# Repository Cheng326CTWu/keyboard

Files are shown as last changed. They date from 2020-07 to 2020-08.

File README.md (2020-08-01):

# 65% keyboard

## Overview

This project was made with the intention of familiarizing myself with the work flow of KiCad. It was also a way to re-learn concepts for schematic captures and the different considerations when laying out a PCB. This repo contains a 65% keyboard PCB design made by referencing tutorials and modifying with new components.

## Software Requirement

* KiCAD

## Tutorial Reference Links

* [RuiQiMao's keyboard tutorial](https://github.com/ruiqimao/keyboard-pcb-guide)
* [ai03's keyboard tutorial](https://wiki.ai03.com/books/pcb-design/page/pcb-guide-part-1---preparations)

## Reference Links

* [Discipline's keyboard repo](https://github.com/coseyfannitutti/discipline)
* [Layer definition in KiCad](https://forum.kicad.info/t/what-is-the-meaning-of-the-layers-in-pcb-new-and-in-the-footprint-editor/9688)
* [BOM in KiCad](https://forum.kicad.info/t/how-to-create-a-bill-of-materials-bom/12346)

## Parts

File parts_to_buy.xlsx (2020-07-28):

Components | Quantity | Value | Package | Sample parts link | Comment
C1 | 1 | 1uF | 0805 | https://www.digikey.ca/en/products/detail/samsung-electro-mechanics/CL21B105KAFNNNE/3889152
C2, C3, C4, C5, C9 | 5 | 0.1uF | 0805 | https://www.digikey.ca/en/products/detail/samsung-electro-mechanics/CL21B104MBCNNNC/3890536
C6 | 1 | 4.7uF | 0805 | https://www.digikey.ca/en/products/detail/yageo/CC0805KKX5R5BB475/2345240
C7, C8 | 2 | 22pF | 0805 | https://www.digikey.ca/en/products/detail/samsung-electro-mechanics/CL21C220JB61PNC/3890691
D1, D2, D3, D4, D5, D6, D7, D8, D9, D10, D11, D12, D13, D14, D15, D16, D17, D18, D19, D20, D21, D22, D23, D24, D25, D26, D27, D28, D29, D30, D31, D32, D33, D34, D35, D36, D37, D38, D39, D40, D41, D42, D43, D44, D45, D46, D47, D48, D49, D50, D51, D52, D53, D54, D55, D56, D57, D58, D59, D60, D61, D62, D63, D64, D65, D66 | 66 | SOD-123 | SOD-123 | https://www.digikey.com/product-detail/en/micro-commercial-co/1N4148W-TP/1N4148WTPMSCT-ND/717311
D67 | 1 | LED | 0805 | https://www.digikey.ca/en/products/detail/broadcom-limited/HSMG-C170/637695
D68, D69 | 2 | 3.6V | 0805 | https://www.digikey.ca/en/products/detail/diodes-incorporated/BZT52C3V6-7-F/814990
 |  |  |  | https://www.digikey.ca/en/products/detail/rohm-semiconductor/RSA5MGTR/2331707 | This one is alternative, as the breakdown voltage range is a bit too big.
F1 | 1 | 500mA | 1206 | https://www.digikey.ca/en/products/detail/bel-fuse-inc/0ZCJ0050AF2E/4156312
J1 | 1 | USB_C_Receptacle | GCT USB4085 | https://www.digikey.ca/en/products/detail/gct/USB4085-GF-A/9859733
MX1, MX2, MX3, MX4, MX5, MX6, MX7, MX8, MX9, MX10, MX11, MX12, MX13, MX16, MX17, MX18, MX19, MX20, MX21, MX22, MX23, MX24, MX25, MX26, MX27, MX30, MX31, MX32, MX33, MX34, MX35, MX36, MX37, MX38, MX39, MX40, MX42, MX44, MX45, MX46, MX47, MX48, MX49, MX50, MX51, MX52, MX53, MX55, MX56, MX58, MX64, MX65, MX66 | 53 | MX-NoLED
MX14 | 1 | MX-NoLED
MX15, MX28 | 2 | MX-NoLED
MX29 | 1 | MX-NoLED
MX41, MX43, MX54 | 3 | MX-NoLED
MX57, MX59, MX61, MX62, MX63 | 5 | MX-NoLED
MX60 | 1 | MX-NoLED
R1, R4 | 2 | 10k | 0805 | https://www.digikey.com/product-detail/en/panasonic-electronic-components/ERA-6AEB103V/P10KDACT-ND/1465971
R2, R3 | 2 | 22 | 0805 | https://www.digikey.com/product-detail/en/panasonic-electronic-components/ERJ-6GEYJ220V/P22ACT-ND/87316
R5, R6 | 2 | 5.1k | 0805 | https://www.digikey.ca/en/products/detail/yageo/RT0805DRE075K1L/1078777
R7, R8 | 2 | 1.5k | 0805 | https://www.digikey.ca/en/products/detail/yageo/RE0805FRE071K5L/5923530
SW1 | 1 | SW_Push | 5.2x5.2mm | https://www.digikey.ca/en/products/detail/c-k/RS-187R05A2-DS-MT-RT/2747199
U1 | 1 | ATmega32U4-AU | 44TQFP 10x10mm | https://www.digikey.ca/en/products/detail/microchip-technology/ATMEGA32U4-AU/1914602
Y1 | 1 | 16MHz | 3.2x2.5mm 4 pads | https://www.digikey.ca/en/products/detail/kyocera-international-inc-electronic-components/CX3225SB16000D0GZJC1/5995241

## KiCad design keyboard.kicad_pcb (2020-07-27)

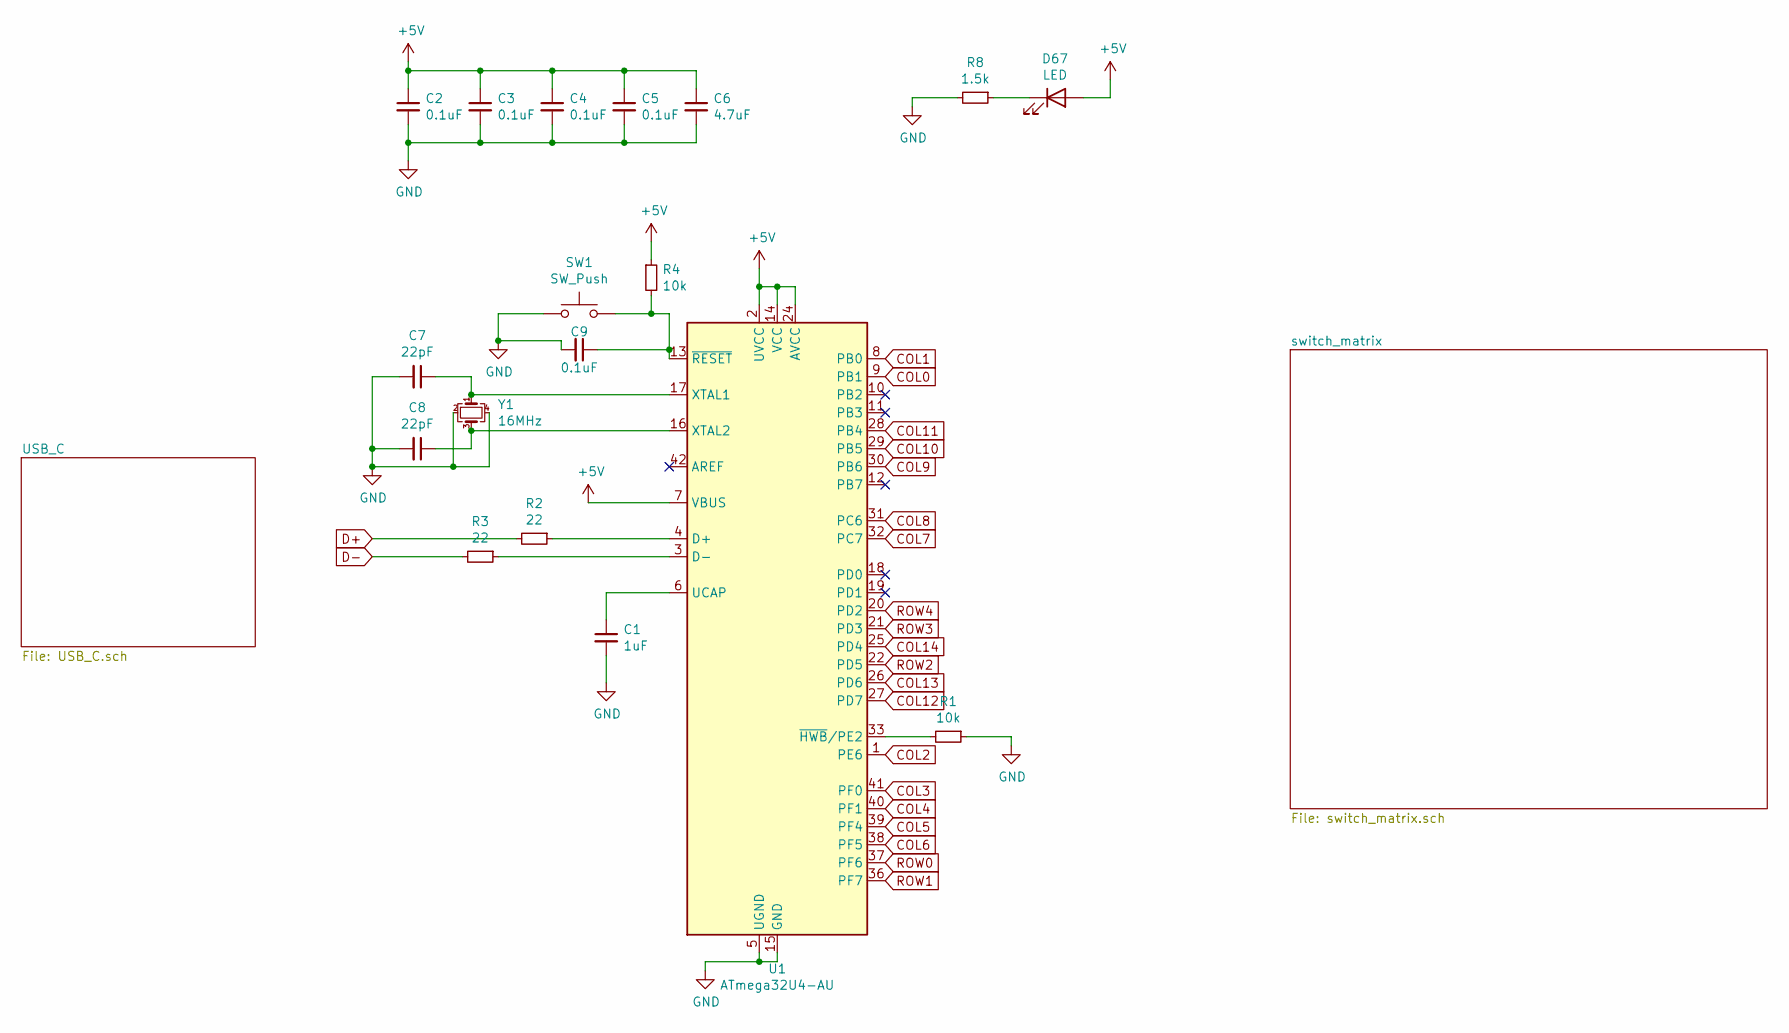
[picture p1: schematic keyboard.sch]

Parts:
C1: 1uF; C_0805_2012Metric
C2, C3, C4, C5, C9: 0.1uF; C_0805_2012Metric
C6: 4.7uF; C_0805_2012Metric
C7, C8: 22pF; C_0805_2012Metric
D67: LED; LED_0805_2012Metric
R1, R4: 10k; R_0805_2012Metric
R2, R3: 22; R_0805_2012Metric
R8: 1.5k; R_0805_2012Metric
SW1: SW_Push; SKQG-1155865
U1: ATmega32U4-AU; TQFP-44_10x10mm_P0.8mm
Y1: 16MHz; Crystal_SMD_3225-4Pin_3.2x2.5mm

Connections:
+5V: C2.1, C3.1, C4.1, C5.1, C6.1, D67.2 (A), R4.1, U1.2 (UVCC), U1.7 (VBUS), U1.14 (VCC), U1.24 (AVCC), U1.34 (VCC), U1.44 (AVCC); also elsewhere on the board
COL0: U1.9 (PB1); also elsewhere on the board
COL1: U1.8 (PB0); also elsewhere on the board
COL2: U1.1 (PE6); also elsewhere on the board
COL3: U1.41 (PF0); also elsewhere on the board
COL4: U1.40 (PF1); also elsewhere on the board
COL5: U1.39 (PF4); also elsewhere on the board
COL6: U1.38 (PF5); also elsewhere on the board
COL7: U1.32 (PC7); also elsewhere on the board
COL8: U1.31 (PC6); also elsewhere on the board
COL9: U1.30 (PB6); also elsewhere on the board
COL10: U1.29 (PB5); also elsewhere on the board
COL11: U1.28 (PB4); also elsewhere on the board
COL12: U1.27 (PD7); also elsewhere on the board
COL13: U1.26 (PD6); also elsewhere on the board
COL14: U1.25 (PD4); also elsewhere on the board
D+: R2.2; also elsewhere on the board
D-: R3.2; also elsewhere on the board
GND: C1.2, C2.2, C3.2, C4.2, C5.2, C6.2, C7.2, C8.2, C9.2, R1.1, R8.2, SW1.1, U1.5 (UGND), U1.15 (GND), U1.23 (GND), U1.35 (GND), U1.43 (GND), Y1.2, Y1.4; also elsewhere on the board
unnamed: C1.1, U1.6 (UCAP)
unnamed: C7.1, U1.17 (XTAL1), Y1.1
unnamed: C8.1, U1.16 (XTAL2), Y1.3
unnamed: C9.1, R4.2, SW1.2, U1.13 (~RESET)
unnamed: D67.1 (K), R8.1
unnamed: R1.2, U1.33 (~HWB~/PE2)
unnamed: R2.1, U1.4 (D+)
unnamed: R3.1, U1.3 (D-)
ROW0: U1.37 (PF6); also elsewhere on the board
ROW1: U1.36 (PF7); also elsewhere on the board
ROW2: U1.22 (PD5); also elsewhere on the board
ROW3: U1.21 (PD3); also elsewhere on the board
ROW4: U1.20 (PD2); also elsewhere on the board

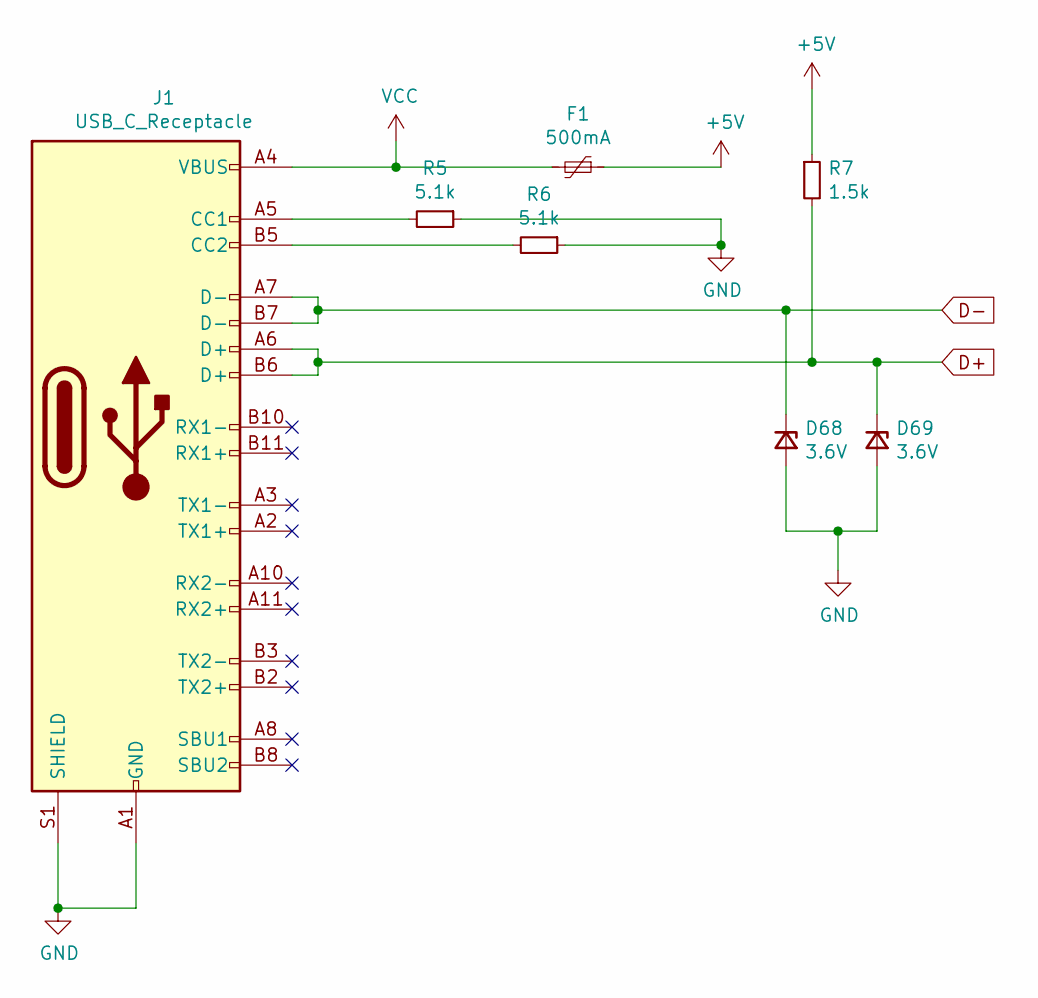
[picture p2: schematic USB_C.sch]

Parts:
D68, D69: 3.6V; D_0805_2012Metric
F1: 500mA; Fuse_1206_3216Metric
J1: USB_C_Receptacle; USB_C_Receptacle_GCT_USB4085
R5, R6: 5.1k; R_0805_2012Metric
R7: 1.5k; R_0805_2012Metric

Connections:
+5V: F1.1, R7.1; also elsewhere on the board
D+: D69.1 (K), J1.A6 (D+), J1.B6 (D+), R7.2; also elsewhere on the board
D-: D68.1 (K), J1.A7 (D-), J1.B7 (D-); also elsewhere on the board
GND: D68.2 (A), D69.2 (A), J1.A1 (GND), J1.A12 (GND), J1.B1 (GND), J1.B12 (GND), J1.S1 (SHIELD), R5.1, R6.1; also elsewhere on the board
unnamed: J1.A5 (CC1), R5.2
unnamed: J1.B5 (CC2), R6.2
VCC: F1.2, J1.A4 (VBUS), J1.A9 (VBUS), J1.B4 (VBUS), J1.B9 (VBUS)

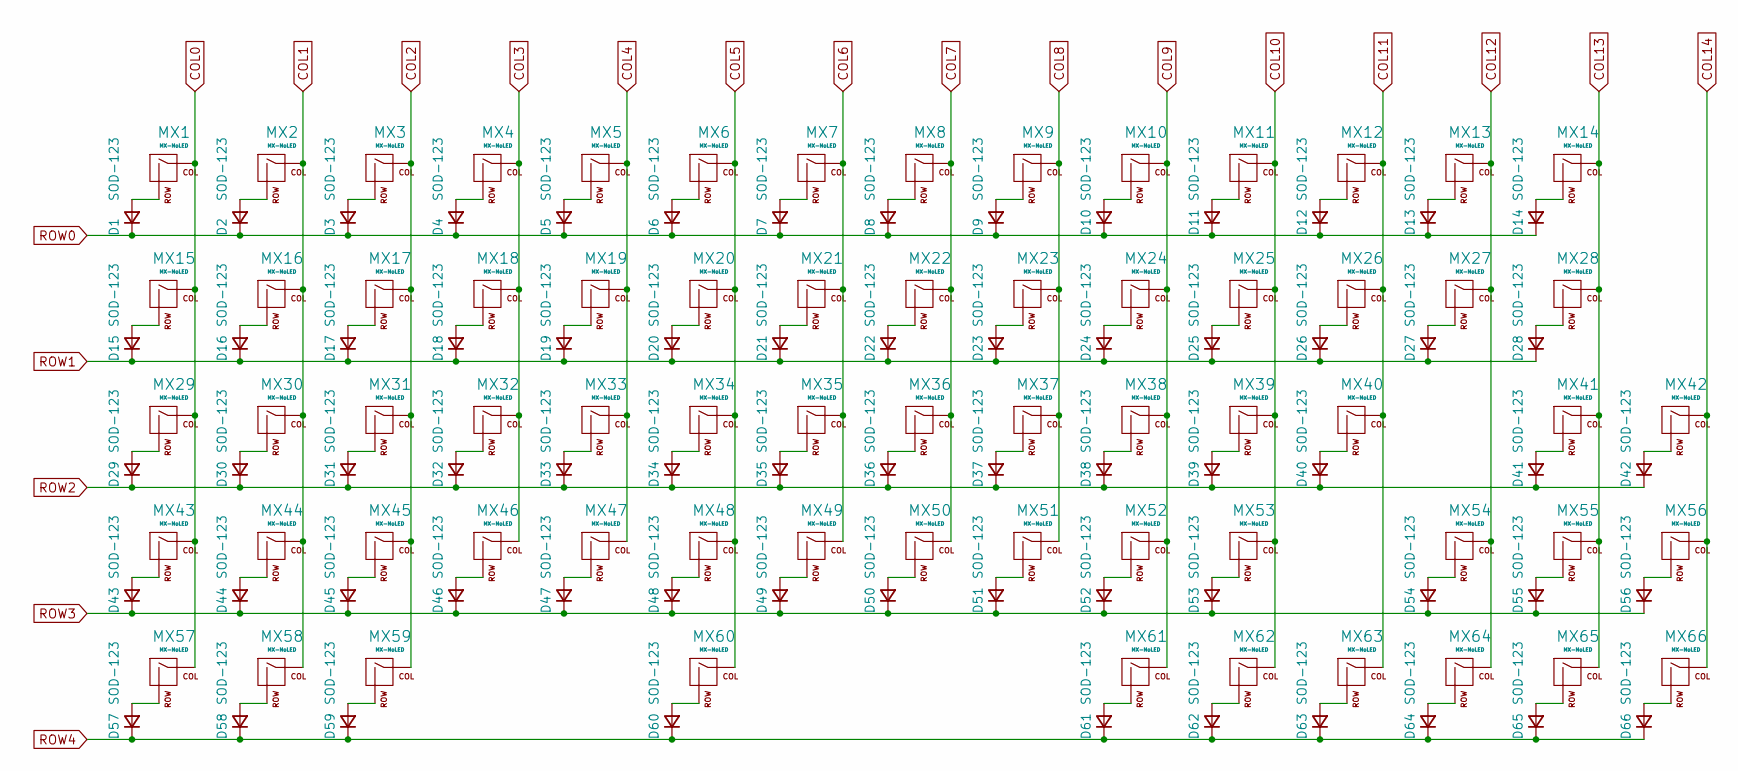
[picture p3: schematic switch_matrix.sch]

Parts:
D1, D2, D3, D4, D5, D6, D7, D8, D9, D10, D11, D12, D13, D14, D15, D16, D17, D18, D19, D20, D21, D22, D23, D24, D25, D26, D27, D28, D29, D30, D31, D32, D33, D34, D35, D36, D37, D38, D39, D40, D41, D42, D43, D44, D45, D46, D47, D48, D49, D50, D51, D52, D53, D54, D55, D56, D57, D58, D59, D60, D61, D62, D63, D64, D65, D66: SOD-123; D_SOD-123
MX1, MX2, MX3, MX4, MX5, MX6, MX7, MX8, MX9, MX10, MX11, MX12, MX13, MX16, MX17, MX18, MX19, MX20, MX21, MX22, MX23, MX24, MX25, MX26, MX27, MX30, MX31, MX32, MX33, MX34, MX35, MX36, MX37, MX38, MX39, MX40, MX42, MX44, MX45, MX46, MX47, MX48, MX49, MX50, MX51, MX52, MX53, MX55, MX56, MX58, MX64, MX65, MX66: MX-NoLED; MXOnly-1U-Hotswap
MX14: MX-NoLED; MXOnly-2U-Hotswap
MX15, MX28: MX-NoLED; MXOnly-1.5U-Hotswap
MX29: MX-NoLED; MXOnly-1.75U-Hotswap
MX41, MX43, MX54: MX-NoLED; MXOnly-2.25U-Hotswap
MX57, MX59, MX61, MX62, MX63: MX-NoLED; MXOnly-1.25U-Hotswap
MX60: MX-NoLED; MXOnly-6.25U-Hotswap

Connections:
COL0: MX1.1 (COL), MX15.1 (COL), MX29.1 (COL), MX43.1 (COL), MX57.1 (COL); also elsewhere on the board
COL1: MX2.1 (COL), MX16.1 (COL), MX30.1 (COL), MX44.1 (COL), MX58.1 (COL); also elsewhere on the board
COL2: MX3.1 (COL), MX17.1 (COL), MX31.1 (COL), MX45.1 (COL), MX59.1 (COL); also elsewhere on the board
COL3: MX4.1 (COL), MX18.1 (COL), MX32.1 (COL), MX46.1 (COL); also elsewhere on the board
COL4: MX5.1 (COL), MX19.1 (COL), MX33.1 (COL), MX47.1 (COL); also elsewhere on the board
COL5: MX6.1 (COL), MX20.1 (COL), MX34.1 (COL), MX48.1 (COL), MX60.1 (COL); also elsewhere on the board
COL6: MX7.1 (COL), MX21.1 (COL), MX35.1 (COL), MX49.1 (COL); also elsewhere on the board
COL7: MX8.1 (COL), MX22.1 (COL), MX36.1 (COL), MX50.1 (COL); also elsewhere on the board
COL8: MX9.1 (COL), MX23.1 (COL), MX37.1 (COL), MX51.1 (COL); also elsewhere on the board
COL9: MX10.1 (COL), MX24.1 (COL), MX38.1 (COL), MX52.1 (COL), MX61.1 (COL); also elsewhere on the board
COL10: MX11.1 (COL), MX25.1 (COL), MX39.1 (COL), MX53.1 (COL), MX62.1 (COL); also elsewhere on the board
COL11: MX12.1 (COL), MX26.1 (COL), MX40.1 (COL), MX63.1 (COL); also elsewhere on the board
COL12: MX13.1 (COL), MX27.1 (COL), MX54.1 (COL), MX64.1 (COL); also elsewhere on the board
COL13: MX14.1 (COL), MX28.1 (COL), MX41.1 (COL), MX55.1 (COL), MX65.1 (COL); also elsewhere on the board
COL14: MX42.1 (COL), MX56.1 (COL), MX66.1 (COL); also elsewhere on the board
unnamed: D1.2 (A), MX1.2 (ROW)
unnamed: D2.2 (A), MX2.2 (ROW)
unnamed: D3.2 (A), MX3.2 (ROW)
unnamed: D4.2 (A), MX4.2 (ROW)
unnamed: D5.2 (A), MX5.2 (ROW)
unnamed: D6.2 (A), MX6.2 (ROW)
unnamed: D7.2 (A), MX7.2 (ROW)
unnamed: D8.2 (A), MX8.2 (ROW)
unnamed: D9.2 (A), MX9.2 (ROW)
unnamed: D10.2 (A), MX10.2 (ROW)
unnamed: D11.2 (A), MX11.2 (ROW)
unnamed: D12.2 (A), MX12.2 (ROW)
unnamed: D13.2 (A), MX13.2 (ROW)
unnamed: D14.2 (A), MX14.2 (ROW)
unnamed: D15.2 (A), MX15.2 (ROW)
unnamed: D16.2 (A), MX16.2 (ROW)
unnamed: D17.2 (A), MX17.2 (ROW)
unnamed: D18.2 (A), MX18.2 (ROW)
unnamed: D19.2 (A), MX19.2 (ROW)
unnamed: D20.2 (A), MX20.2 (ROW)
unnamed: D21.2 (A), MX21.2 (ROW)
unnamed: D22.2 (A), MX22.2 (ROW)
unnamed: D23.2 (A), MX23.2 (ROW)
unnamed: D24.2 (A), MX24.2 (ROW)
unnamed: D25.2 (A), MX25.2 (ROW)
unnamed: D26.2 (A), MX26.2 (ROW)
unnamed: D27.2 (A), MX27.2 (ROW)
unnamed: D28.2 (A), MX28.2 (ROW)
unnamed: D29.2 (A), MX29.2 (ROW)
unnamed: D30.2 (A), MX30.2 (ROW)
unnamed: D31.2 (A), MX31.2 (ROW)
unnamed: D32.2 (A), MX32.2 (ROW)
unnamed: D33.2 (A), MX33.2 (ROW)
unnamed: D34.2 (A), MX34.2 (ROW)
unnamed: D35.2 (A), MX35.2 (ROW)
unnamed: D36.2 (A), MX36.2 (ROW)
unnamed: D37.2 (A), MX37.2 (ROW)
unnamed: D38.2 (A), MX38.2 (ROW)
unnamed: D39.2 (A), MX39.2 (ROW)
unnamed: D40.2 (A), MX40.2 (ROW)
unnamed: D41.2 (A), MX41.2 (ROW)
unnamed: D42.2 (A), MX42.2 (ROW)
unnamed: D43.2 (A), MX43.2 (ROW)
unnamed: D44.2 (A), MX44.2 (ROW)
unnamed: D45.2 (A), MX45.2 (ROW)
unnamed: D46.2 (A), MX46.2 (ROW)
unnamed: D47.2 (A), MX47.2 (ROW)
unnamed: D48.2 (A), MX48.2 (ROW)
unnamed: D49.2 (A), MX49.2 (ROW)
unnamed: D50.2 (A), MX50.2 (ROW)
unnamed: D51.2 (A), MX51.2 (ROW)
unnamed: D52.2 (A), MX52.2 (ROW)
unnamed: D53.2 (A), MX53.2 (ROW)
unnamed: D54.2 (A), MX54.2 (ROW)
unnamed: D55.2 (A), MX55.2 (ROW)
unnamed: D56.2 (A), MX56.2 (ROW)
unnamed: D57.2 (A), MX57.2 (ROW)
unnamed: D58.2 (A), MX58.2 (ROW)
unnamed: D59.2 (A), MX59.2 (ROW)
unnamed: D60.2 (A), MX60.2 (ROW)
unnamed: D61.2 (A), MX61.2 (ROW)
unnamed: D62.2 (A), MX62.2 (ROW)
unnamed: D63.2 (A), MX63.2 (ROW)
unnamed: D64.2 (A), MX64.2 (ROW)
unnamed: D65.2 (A), MX65.2 (ROW)
unnamed: D66.2 (A), MX66.2 (ROW)
ROW0: D1.1 (K), D2.1 (K), D3.1 (K), D4.1 (K), D5.1 (K), D6.1 (K), D7.1 (K), D8.1 (K), D9.1 (K), D10.1 (K), D11.1 (K), D12.1 (K), D13.1 (K), D14.1 (K); also elsewhere on the board
ROW1: D15.1 (K), D16.1 (K), D17.1 (K), D18.1 (K), D19.1 (K), D20.1 (K), D21.1 (K), D22.1 (K), D23.1 (K), D24.1 (K), D25.1 (K), D26.1 (K), D27.1 (K), D28.1 (K); also elsewhere on the board
ROW2: D29.1 (K), D30.1 (K), D31.1 (K), D32.1 (K), D33.1 (K), D34.1 (K), D35.1 (K), D36.1 (K), D37.1 (K), D38.1 (K), D39.1 (K), D40.1 (K), D41.1 (K), D42.1 (K); also elsewhere on the board
ROW3: D43.1 (K), D44.1 (K), D45.1 (K), D46.1 (K), D47.1 (K), D48.1 (K), D49.1 (K), D50.1 (K), D51.1 (K), D52.1 (K), D53.1 (K), D54.1 (K), D55.1 (K), D56.1 (K); also elsewhere on the board
ROW4: D57.1 (K), D58.1 (K), D59.1 (K), D60.1 (K), D61.1 (K), D62.1 (K), D63.1 (K), D64.1 (K), D65.1 (K), D66.1 (K); also elsewhere on the board

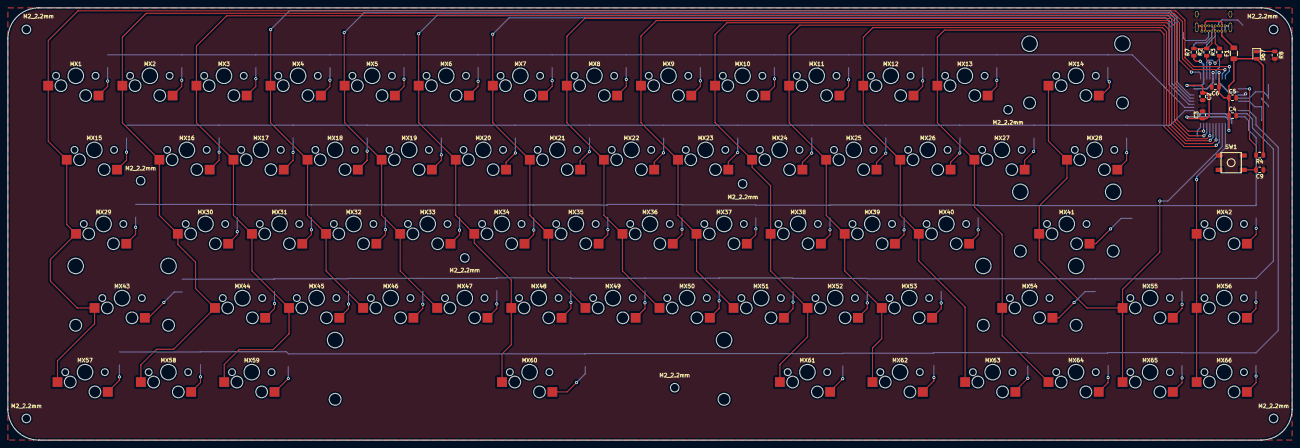
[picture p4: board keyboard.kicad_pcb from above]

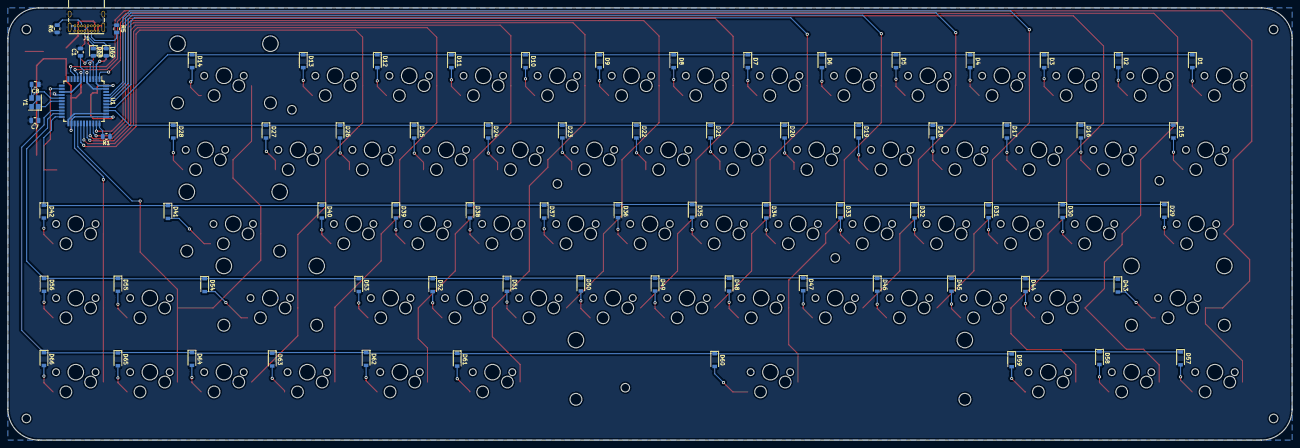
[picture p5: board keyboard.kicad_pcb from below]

Board: 2 copper layers, 330.2 x 111.1 mm, 166 parts (143 on the bottom side), 101 nets.

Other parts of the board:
M2_2.2mm, M2_2.2mm#2, M2_2.2mm#3, M2_2.2mm#4, M2_2.2mm#5, M2_2.2mm#6, M2_2.2mm#7, M2_2.2mm#8, M2_2.2mm#9: MountingHole_2.2mm_M2

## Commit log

2020-07-21 Added schematic and footprint library
2020-07-21 Wired MCU and USB C
    [USB_C.sch, keyboard_matrix.sch]
2020-07-21 Renamed keyboard_matrix to switch_matrix
    [USB_C.sch, keyboard.sch, switch_matrix.sch]
2020-07-21 Delete keyboard_matrix.sch
    keyboard_matrix was renamed to switch_matrix but file was not deleted in repo
    [keyboard_matrix.sch]
2020-07-21 Wired switch matrix
    [switch_matrix.sch]
2020-07-22 Assigned footprint
    [USB_C.sch, keyboard.sch, switch_matrix.sch]
2020-07-22 Rough layout of PCB
2020-07-23 Changed PCB layout
    [keyboard.kicad_pcb]
2020-07-27 Finished routing, filled in ground planes, checked with DRC and 3D render
    [keyboard.kicad_pcb, keyboard.sch]
2020-07-27 adjusted mounting holes, added dimension lines
    [keyboard.kicad_pcb]
2020-07-28 Added BOM
    [parts_to_buy.xlsx]
2020-07-28 generated gerber and drill files
    [keyboard-B_Cu.gbl, keyboard-B_Mask.gbs, keyboard-B_Paste.gbp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]
2020-07-28 created gerber zip file
